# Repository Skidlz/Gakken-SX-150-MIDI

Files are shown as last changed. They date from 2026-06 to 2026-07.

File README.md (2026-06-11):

This project adds MIDI support to the Gakken SX-150 mk II using an Arduino R4.

This includes CCs for all original controls, plus additional parameters.

## Additional Hardware Features:
- Sustain and Release Stages (for existing hardware envelope)
- Inverted Envelope Mode
- Pulse, Dual Pulse, Super Saw, and other Waveforms
- Pulse Width Modulation
- Square and Triangle Sub Oscillators
- VCF Drive adjustment
- Envelope to VCF Depth Adjustment
- High Pass Filter Mode
- LFO to VCF Modulation
- Improved LFO sync
- VCA
- LED indicators for LFO and Envelope

## Additional Software Features:
 - Extra Software Envelopes with S/H
 - Extra Software LFOs
 - Pitch Bend
 - Portamento
 - Legato
 - Velocity-triggered Accent
 - Velocity Modulation
 - VCF Keytracking
 - Delay and Fade-in for Hardware LFO
 - Quantizing for Touchstrip

## Routing Diagram
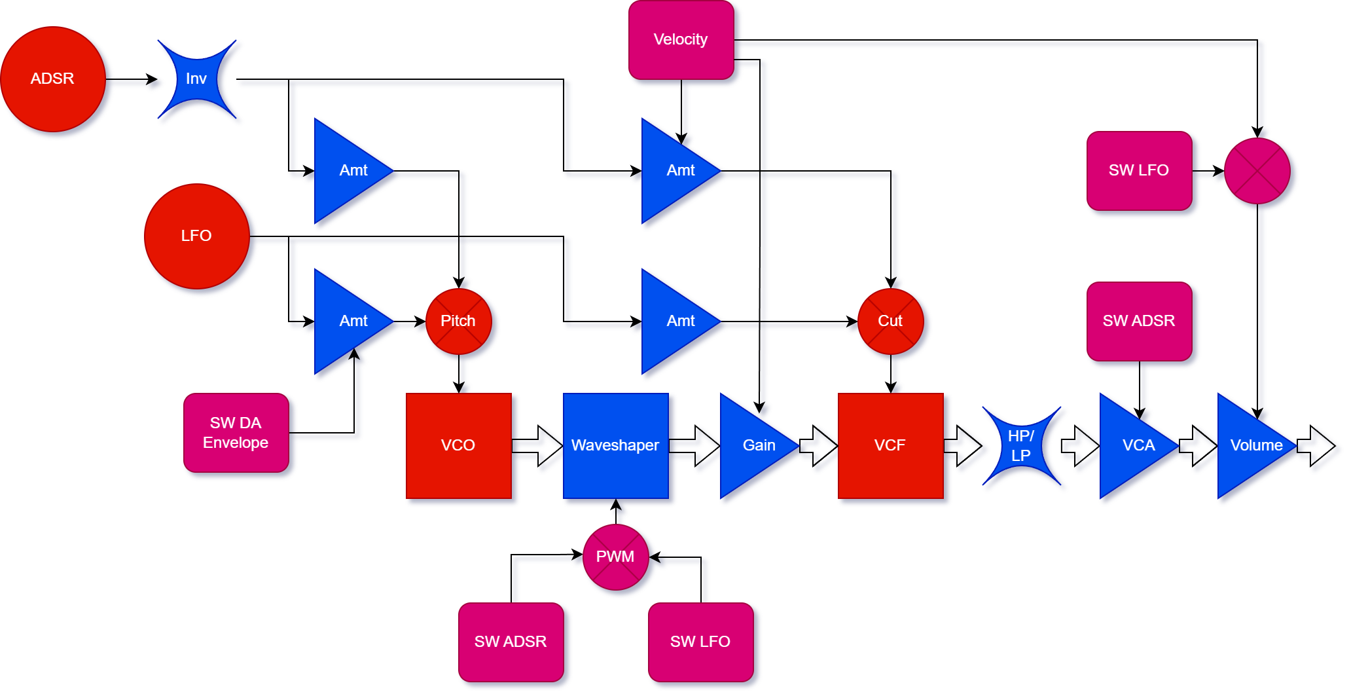
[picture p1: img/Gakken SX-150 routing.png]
Routing Diagram


## Schematic Diagram
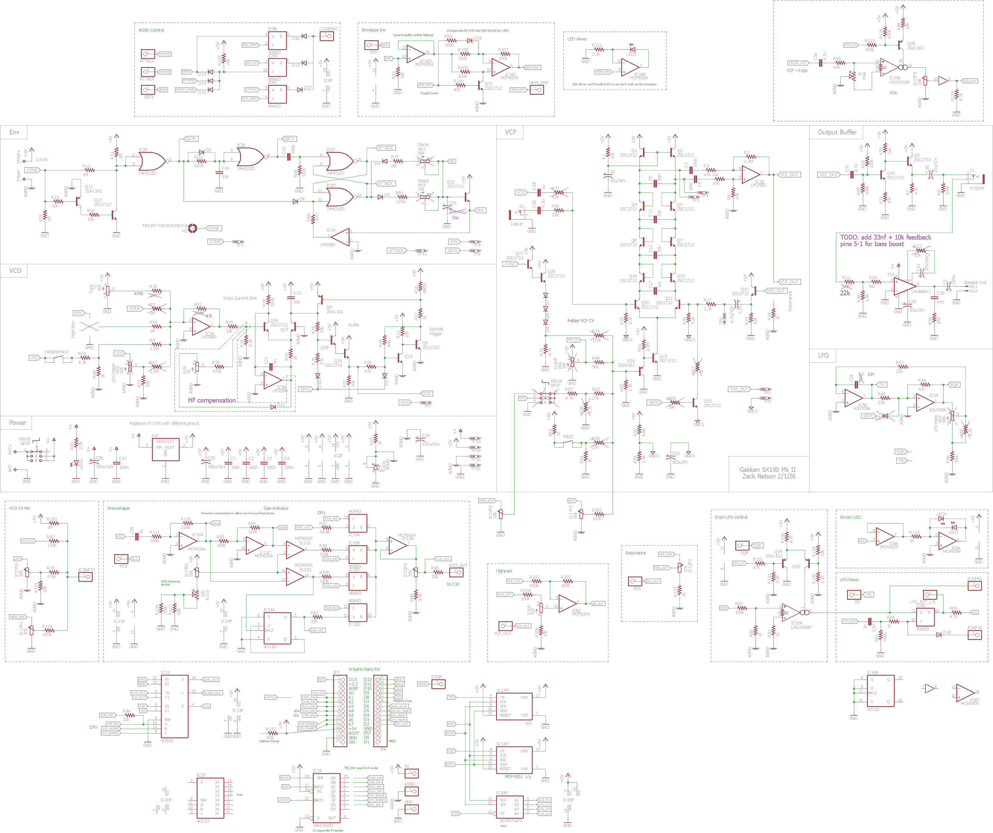
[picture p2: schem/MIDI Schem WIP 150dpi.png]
Schematic


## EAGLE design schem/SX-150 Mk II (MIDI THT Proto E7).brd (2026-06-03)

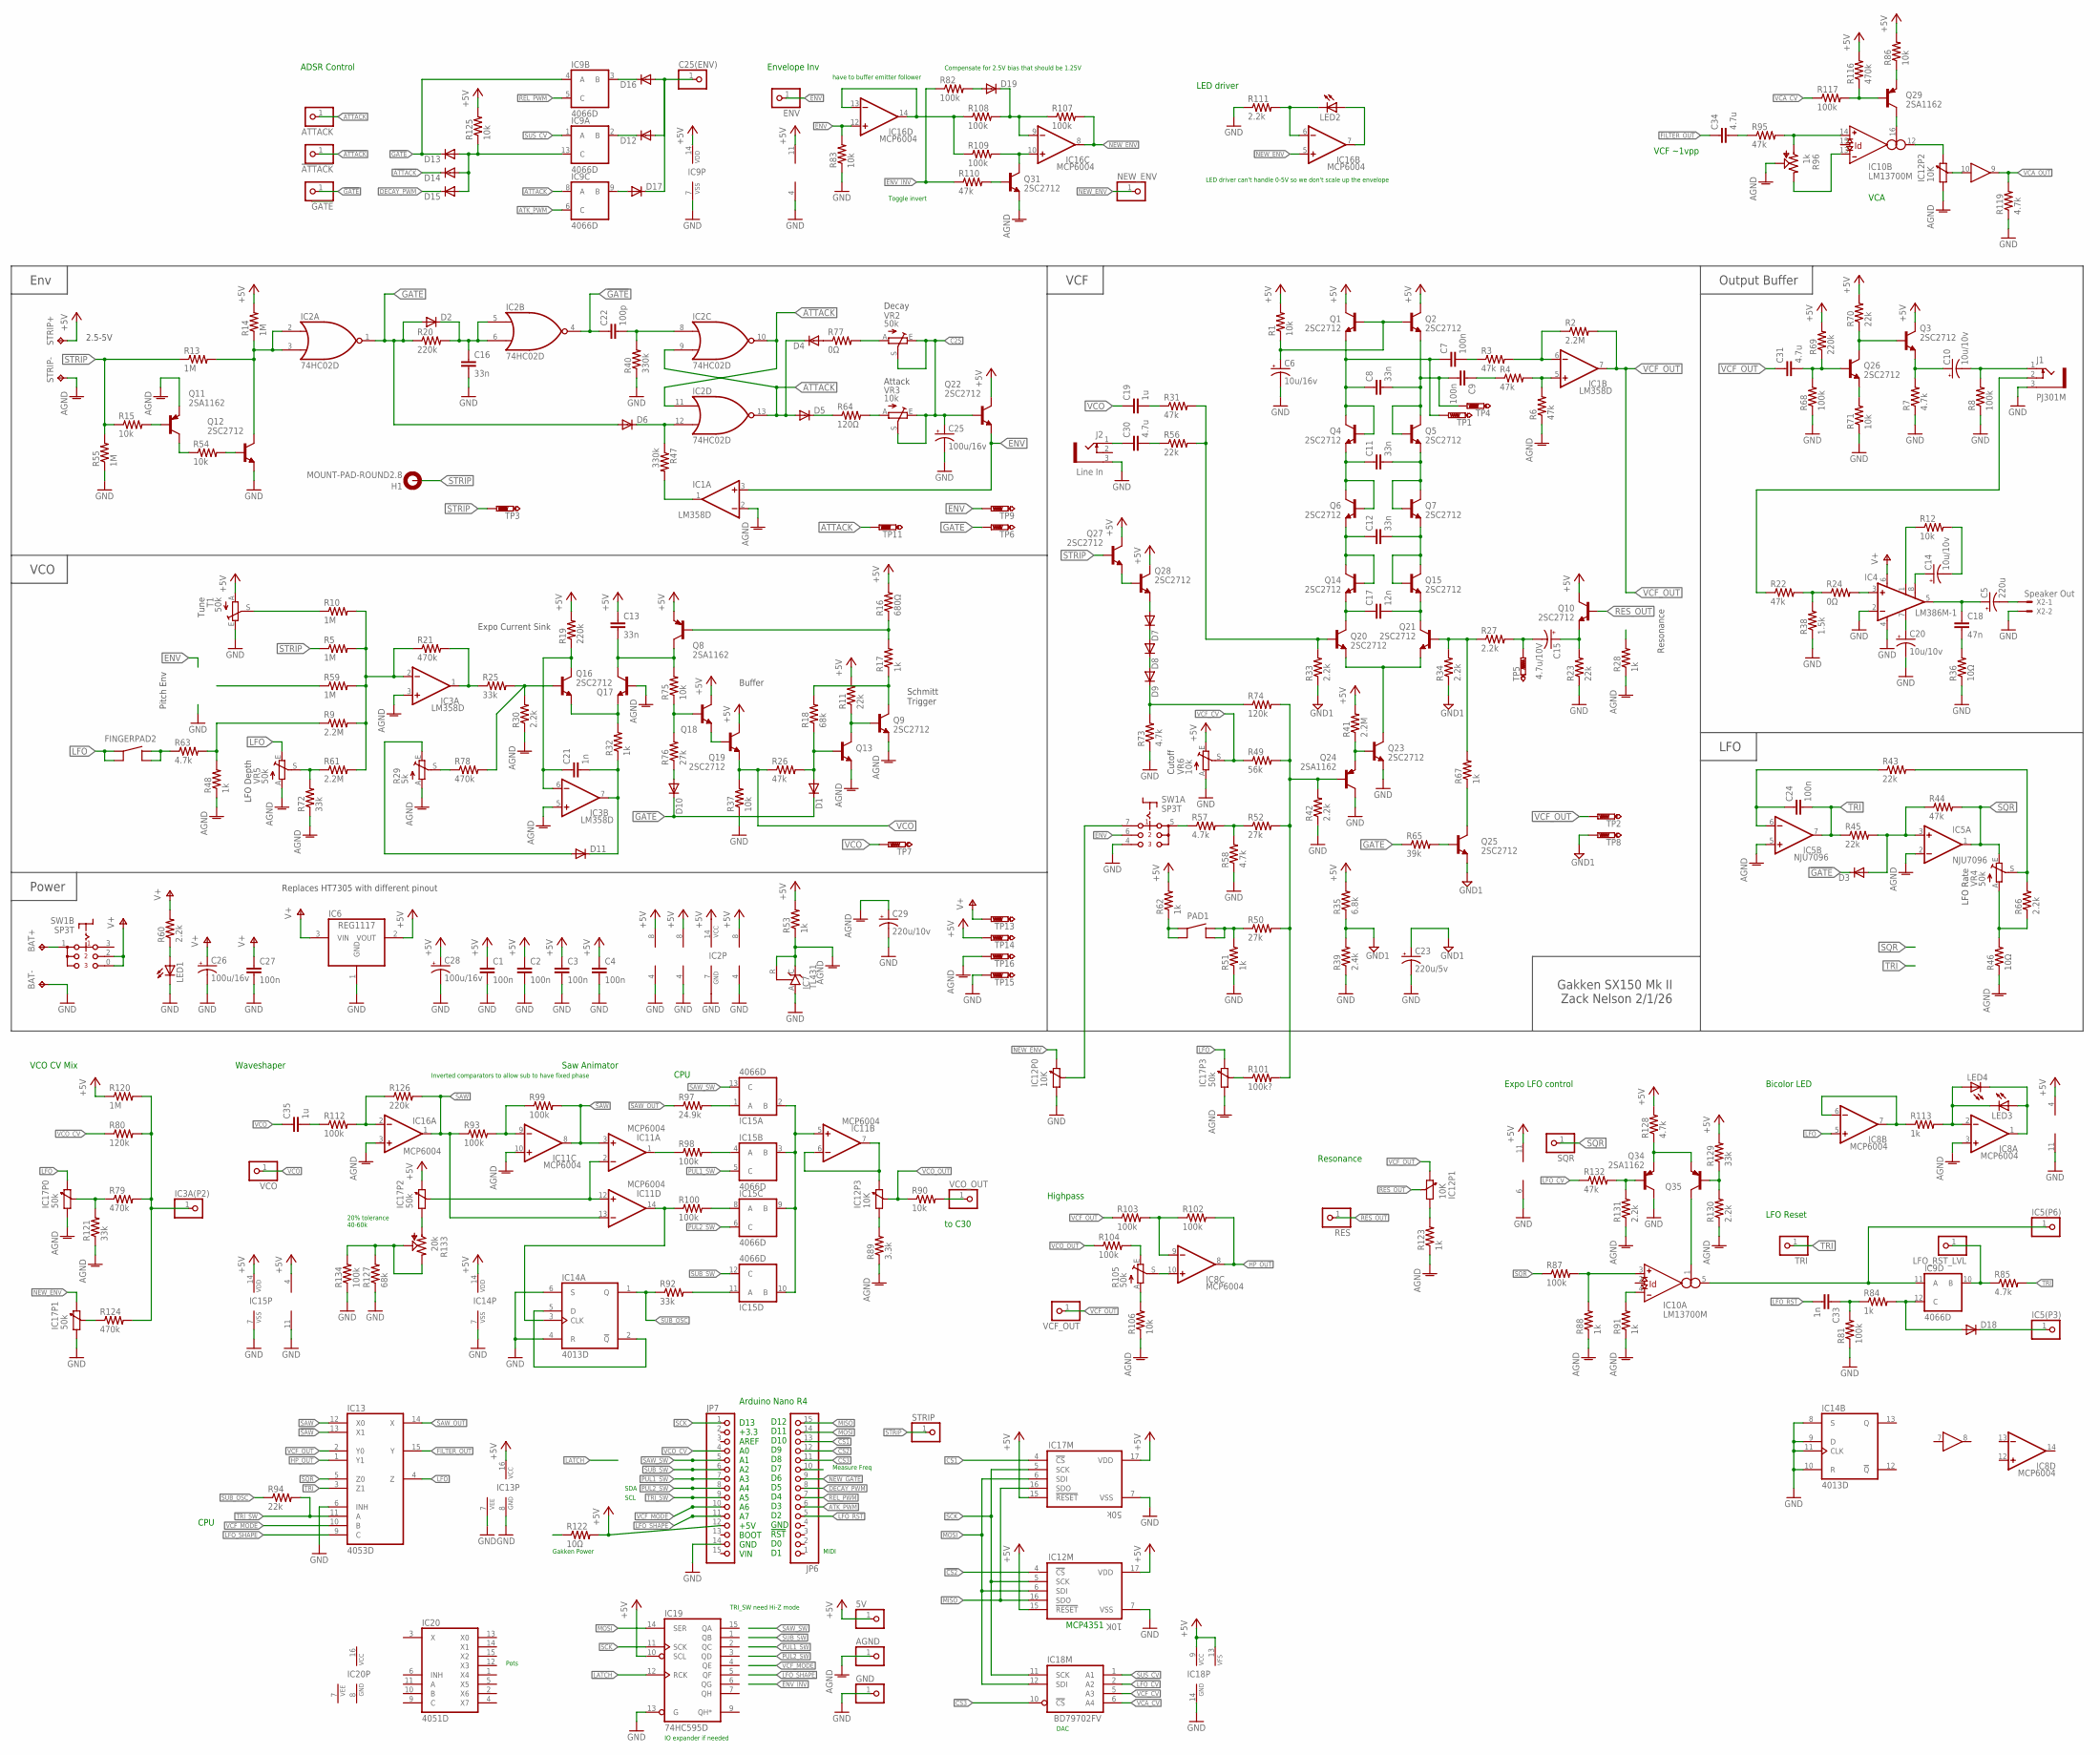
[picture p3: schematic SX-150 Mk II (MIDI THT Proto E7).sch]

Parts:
5V: PINHD-1X1; 1X01
!ATTACK: PINHD-1X1; 1X01
!GATE: PINHD-1X1; 1X01
AGND: PINHD-1X1; 1X01
ATTACK: PINHD-1X1; 1X01
BAT+: TPPAD1-13; P1-13
BAT-: TPPAD1-13; P1-13
C1, C2, C3, C4, C7, C9, C24, C27: 100n; C0603
C5: 220u; E2,5-6
C6: 10u/16v; E2,5-6
C8, C11, C12, C13, C16: 33n; C0603
C10, C14, C20: 10u/10v; E2,5-6
C15: 4.7u/10V; E2,5-6
C17: 12n; C0603
C18: 47n; C0603
C19, C35: 1u; C0603
C21, C33: 1n; C0603
C22: 100p; C0603
C23: 220u/5v; E2,5-6
C25, C26, C28: 100u/16v; E2,5-6
C25(ENV): PINHD-1X1; 1X01
C29: 220u/10v; E2,5-6
C30, C31, C34: 4.7u; C0603
D1, D10, D11: DIODE-DO41-7.6; DO41-7.6
D2, D3, D4, D5, D6, D7, D8, D9, D12, D13, D14, D15, D16, D17, D18, D19: DIODE-MINIMELF; MINIMELF
ENV: PINHD-1X1; 1X01
FINGERPAD2: GAKKEN-PAD
GND: PINHD-1X1; 1X01
H1: MOUNT-PAD-ROUND2.8; 2,8-PAD
IC1, IC3: LM358D; SO08
IC2: 74HC02D; SO14
IC3A(P2), IC5(P3), IC5(P6): PINHD-1X1; 1X01
IC4: LM386M-1; SO08
IC5: NJU7096; SO08
IC6: REG1117; SOT223
IC7: TL431; TO92-CLP
IC8, IC11, IC16: MCP6004; SO14
IC9, IC15: 4066D; SO14
IC10: LM13700M; SO16
IC12: 10K; TSSOP20_MC_MCH
IC13: 4053D; SO16
IC14: 4013D; SO14
IC17: 50k; TSSOP20_MC_MCH
IC18: BD79702FV; TSSOP14
IC19: 74HC595D; SO16
IC20: 4051D; SO16
J1: PJ301M; JACK-3.5-NOHOLE
J2: Line In; JACK-3.5-NOHOLE
JP6, JP7: PINHD-1X15; 1X15
LED1, LED2, LED3, LED4: LED3MM
LFO_RST_LVL: PINHD-1X1; 1X01
NEW_ENV: PINHD-1X1; 1X01
PAD1: GAKKEN-PAD
Q1, Q2, Q3, Q4, Q5, Q6, Q7, Q9, Q10, Q12, Q13, Q14, Q15, Q16, Q17, Q18, Q19, Q20, Q21, Q22, Q23, Q25, Q26, Q27, Q28, Q31: 2SC2712; SOT23-BEC
Q8, Q11, Q24, Q29, Q34, Q35: 2SA1162; SOT23-BEC
R1, R12, R15, R37, R54, R71, R75, R83, R86, R90, R106, R125: 10k; R0603
R2, R9, R41, R61: 2.2M; R0603
R3, R4, R6, R22, R26, R31, R44, R95, R110, R132: 47k; R0603
R5, R10, R13, R14, R55, R59, R120: 1M; R0603
R7, R57, R58, R63, R73, R85, R119, R128: 4.7k; R0603
R8, R68, R81, R82, R87, R93, R98, R99, R100, R102, R103, R104, R107, R108, R109, R112, R117, R134: 100k; R0603
R11, R23, R43, R45, R56, R70, R94: 22k; R0603
R16: 680Ω; R0603
R17, R28, R32, R48, R51, R53, R62, R67, R84, R88, R91, R113, R123: 1k; R0603
R18, R127: 68k; R0603
R19, R20, R69, R126: 220k; R0603
R21, R78, R79, R116, R124: 470k; R0603
R24, R77: 0Ω; R0603
R25, R72, R92, R121, R129: 33k; R0603
R27, R30, R33, R34, R42, R60, R66, R111, R130, R131: 2.2k; R0603
R29: 5k; B25P
R35: 6.8k; R0603
R36, R46, R122: 10Ω; R0603
R38: 1.5k; R0603
R39: 2.4k; R0603
R40, R47: 330k; R0603
R49: 56k; R0603
R50, R52, R76: 27k; R0603
R64: 120Ω; R0603
R65: 39k; R0603
R74, R80: 120k; R0603
R89: 3.3k; R0603
R96: 1k; B25P
R97: 24.9k; R0603
R101: 100k?; R0603
R105: 50k; B25P
R133: 20k; B25P
RES: PINHD-1X1; 1X01
SQR: PINHD-1X1; 1X01
STRIP: PINHD-1X1; 1X01
STRIP+: TPB2,54; B2,54
STRIP-: TPB2,54; B2,54
SW1: SP3T
T1: 50k; CA9V
TP1, TP2, TP3, TP4, TP5, TP6, TP7, TP8, TP9, TP11, TP13, TP14, TP15, TP16: PTR1B1,27; B1,27
TRI: PINHD-1X1; 1X01
VCF_OUT: PINHD-1X1; 1X01
VCO: PINHD-1X1; 1X01
VCO_OUT: PINHD-1X1; 1X01
VR2, VR4, VR5: 50k; CA9V
VR3, VR6: 10k; CA9V
X2: Speaker Out; 22-23-2021

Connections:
!ATTACK: !ATTACK.1, D14.C, IC2.10 (O), IC2.11 (I0)
!CS1: IC17.4 (!CS), JP6.13
!CS2: IC12.4 (!CS), JP6.12
!CS3: IC18.10 (!CS), JP6.11
!GATE: !GATE.1, C22.1, D1.C, D3.C, D10.C, D13.C, IC2.4 (O), IC9.4 (A)
!SAW: IC11.3 (+IN), IC11.8 (OUT), IC13.13 (X1), R99.2
+5V: 5V.1, C1.1, C2.1, C3.1, C4.1, C13.1, C28.+, IC1.8 (V+), IC2.14 (VCC), IC3.8 (V+), IC5.8 (V+), IC6.2 (VOUT), IC8.4 (V+), IC9.14 (VDD), IC10.11 (V+), IC11.4 (V+), IC12.15 (!RESET), IC12.17 (VDD), IC13.16 (VCC), IC14.14 (VDD), IC15.14 (VDD), IC16.11 (V-), IC17.15 (!RESET), IC17.17 (VDD), IC17.18 (B), IC18.9 (VCC), IC18.13 (VFS), IC19.10 (SCL), JP7.12, Q1.C, Q2.C, Q3.C, Q8.E, Q10.C, Q18.C, Q19.C, Q22.C, Q27.C, Q28.C, R1.2, R11.2, R14.2, R16.2, R19.2, R35.2, R41.2, R53.2, R62.2, R69.2, R70.2, R86.2, R116.2, R120.1, R122.2, R125.2, R128.2, R129.2, STRIP+.TP, T1.A, TP14.TP, VR6.E
AGND: AGND.1, C29.+, IC1.2 (-IN), IC3.3 (+IN), IC3.5 (+IN), IC5.2 (-IN), IC5.5 (+IN), IC7.C, IC7.R, IC8.3 (+IN), IC11.10 (+IN), IC12.20 (A), IC16.3 (+IN), IC17.1 (A), IC17.11 (A), Q9.E, Q11.E, Q13.E, Q17.B, Q31.E, R6.1, R28.1, R29.A, R30.1, R46.1, R48.1, R53.1, R72.1, R88.1, R89.1, R91.1, R96.S, R106.1, R121.1, R123.1, R130.1, R131.1, STRIP-.TP, TP16.TP, VR5.A
ATK_PWM: IC9.6 (C), JP6.6
ATTACK: ATTACK.1, D4.C, D5.A, IC2.9 (I1), IC2.13 (O), IC9.8 (A), TP11.TP
C25: C25.+, C25(ENV).1, D12.A, D16.A, D17.C, Q22.B, VR2.E, VR2.S, VR3.E, VR3.S
DECAY_PWM: D15.C, JP6.8
ENV: ENV.1, IC1.3 (+IN), IC16.12 (+IN), Q22.E, R83.2, SW1.6 (T2), TP9.TP
ENV_INV: R82.1, R110.1
FILTER_OUT: C34.1, IC13.15 (Y)
GATE: D2.A, D6.A, IC2.1 (O), R20.1, R65.1, TP6.TP
GND: BAT-.TP, C1.2, C2.2, C3.2, C4.2, C6.-, C16.2, C20.-, C23.-, C25.-, C26.-, C27.2, C28.-, C29.-, GND.1, IC1.4 (V-), IC2.7 (GND), IC3.4 (V-), IC4.2 (-IN), IC4.4 (GND), IC5.4 (V-), IC6.1 (GND), IC7.A, IC8.11 (V-), IC9.7 (VSS), IC10.6 (V-), IC11.11 (V-), IC12.7 (VSS), IC12.11 (A), IC13.6 (INH), IC13.7 (VEE), IC13.8 (GND), IC14.4 (R), IC14.6 (S), IC14.7 (VSS), IC14.8 (S), IC14.9 (D), IC14.10 (R), IC14.11 (CLK), IC15.7 (VSS), IC16.4 (V+), IC17.7 (VSS), IC17.10 (A), IC18.14 (GND), IC19.8 (GND), IC19.13 (G), IC20.8 (GND), J1.3 (1), J2.3 (1), JP7.14, LED1.K (C), Q12.E, Q23.E, Q24.C, Q34.C, R7.1, R8.1, R23.1, R36.1, R37.1, R38.1, R39.1, R40.1, R42.1, R51.1, R55.1, R58.1, R68.1, R71.1, R73.1, R81.1, R83.1, R111.1, R119.1, R127.1, R134.1, SW1.4 (T3), T1.E, TP15.TP, VR6.A, X2.2
GND1: C23.+, Q25.E, R33.1, R34.1, R35.1, R39.2, TP8.TP
HP_OUT: IC8.8 (OUT), IC13.1 (Y1), R102.2
LATCH: IC19.12 (RCK)
LFO: FINGERPAD2.A0, FINGERPAD2.A1, IC8.5 (+IN), IC13.4 (Z), IC17.3 (B), IC17.13 (B), VR5.E
LFO_CV: IC18.2 (A2), R132.1
LFO_RST: C33.2, JP6.5
LFO_SHAPE: IC13.9 (C), JP7.11
MISO: IC12.16 (SDO), IC17.16 (SDO), JP6.15
MOSI: IC12.6 (SDI), IC17.6 (SDI), IC18.12 (SDI), IC19.14 (SER), JP6.14
unnamed: IC1.1 (OUT), R47.2
unnamed: D5.C, R64.1
unnamed: IC2.2 (I0), IC2.3 (I1), Q12.C, R13.2, R14.1
unnamed: D12.C, IC9.2 (B)
unnamed: C22.2, IC2.8 (I0), R40.2
unnamed: Q12.B, R54.2
unnamed: C16.1, D2.C, IC2.5 (I0), IC2.6 (I1), R20.2
unnamed: D6.C, IC2.12 (I1), R47.1
unnamed: D4.A, R77.1
unnamed: D17.A, IC9.9 (B)
unnamed: R64.2, VR3.A
unnamed: D19.A, R82.2
unnamed: Q11.C, R54.1
unnamed: Q11.B, R15.2
unnamed: R61.1, R72.2, VR5.S
unnamed: IC5(P6).1, IC9.11 (A), IC10.5 (OUT)
unnamed: IC3.2 (-IN), R5.2, R9.2, R10.2, R21.1, R59.2, R61.2
unnamed: D18.C, IC5(P3).1
unnamed: R46.2, R66.1, VR4.A
unnamed: R43.2, R66.2, VR4.S
unnamed: IC3.1 (OUT), R21.2, R25.1
unnamed: Q16.B, R25.2, R30.2, R78.2
unnamed: R9.1, R48.2, R63.2
unnamed: R10.1, T1.S
unnamed: C13.2, Q8.C, Q17.C, R75.2
unnamed: Q8.B, R16.1, R17.2
unnamed: C21.2, D11.C, IC3.7 (OUT), R32.1
unnamed: Q16.E, Q17.E, R32.2
unnamed: C21.1, IC3.6 (-IN), Q16.C, R19.1
unnamed: Q9.C, R17.1, R18.2
unnamed: Q18.B, R75.1, R76.2
unnamed: Q18.E, Q19.B
unnamed: BAT+.TP, SW1.1
unnamed: Q9.B, Q13.C, R11.1
unnamed: D1.A, Q13.B, R18.1, R26.2
unnamed: D10.A, R76.1
unnamed: C7.1, C8.1, Q1.E, Q4.B, Q4.C, TP1.TP
unnamed: C8.2, C9.2, Q2.E, Q5.B, Q5.C, TP4.TP
unnamed: C6.+, Q1.B, Q2.B, R1.1
unnamed: Q20.E, Q21.E, Q23.C
unnamed: C11.1, Q4.E, Q6.B, Q6.C
unnamed: C11.2, Q5.E, Q7.B, Q7.C
unnamed: Q20.B, R31.2, R33.2, R56.2
unnamed: C12.1, Q6.E, Q14.B, Q14.C
unnamed: C12.2, Q7.E, Q15.B, Q15.C
unnamed: C17.1, Q14.E, Q20.C
unnamed: C17.2, Q15.E, Q21.C
unnamed: Q21.B, R27.1, R34.2, R67.2
unnamed: C7.2, R3.1
unnamed: C9.1, R4.1
unnamed: IC1.6 (-IN), R2.1, R3.2
unnamed: IC1.5 (+IN), R4.2, R6.2
unnamed: Q23.B, Q24.E, R41.1
unnamed: Q25.C, R67.1
unnamed: Q25.B, R65.2
unnamed: C15.-, R27.2, TP5.TP
unnamed: C15.+, Q10.E, R23.2
unnamed: IC17.9 (W), R124.1
unnamed: Q29.E, R86.1
unnamed: Q24.B, R42.2, R49.2, R50.2, R52.2, R74.2, R101.2
unnamed: R57.1, SW1.5 (P1)
unnamed: C35.2, R112.1
unnamed: R52.1, R57.2, R58.2
unnamed: PAD1.B0, PAD1.B1, R50.1, R51.2
unnamed: C19.2, R31.1
unnamed: C30.2, R56.1
unnamed: C30.1, J2.1 (2)
unnamed: C31.2, Q26.B, R68.2, R69.1
unnamed: Q3.B, Q26.C, R70.1
unnamed: Q26.E, R71.2
unnamed: C10.+, Q3.E, R7.2
unnamed: C10.-, J1.1 (2), R8.2
unnamed: Q27.E, Q28.B
unnamed: PAD1.A0, PAD1.A1, R62.1
unnamed: D7.A, Q28.E
unnamed: D7.C, D8.A
unnamed: D8.C, D9.A
unnamed: D9.C, R73.2, R74.1
unnamed: FINGERPAD2.B0, FINGERPAD2.B1, R63.1
unnamed: C20.+, IC4.7 (BYPASS)
unnamed: C14.+, IC4.8 (GAIN)
unnamed: IC4.1 (GAIN), R12.1
unnamed: C14.-, R12.2
unnamed: C5.+, C18.1, IC4.5 (OUT)
unnamed: IC4.3 (+IN), R24.2
unnamed: C5.-, X2.1
unnamed: J1.2 (3), R22.1
unnamed: C18.2, R36.2
unnamed: D11.A, R29.E
unnamed: R22.2, R24.1, R38.2
unnamed: LED1.A, R60.1
unnamed: IC10.16 (IABC), Q29.C
unnamed: R29.S, R78.1
unnamed: D13.A, D14.A, D15.A, IC9.13 (C), R125.1
unnamed: C24.1, IC5.6 (-IN), R43.1
unnamed: D19.C, IC16.9 (-IN), R107.1, R108.2
unnamed: D16.C, IC9.3 (B)
unnamed: R77.2, VR2.A
unnamed: D18.A, IC9.12 (C), R84.2
unnamed: IC11.1 (OUT), R98.1
unnamed: IC8.10 (+IN), R105.S
unnamed: IC16.13 (-IN), IC16.14 (OUT), R108.1, R109.1
unnamed: C33.1, R81.2, R84.1
unnamed: IC14.2 (!Q), IC14.5 (D)
unnamed: IC12.12 (W), SW1.7 (T1)
unnamed: IC10.3 (+IN), R87.2, R88.2
unnamed: IC10.4 (-IN), R91.2
unnamed: IC15.1 (A), R97.2
unnamed: IC15.4 (A), R98.2
unnamed: IC15.8 (A), R100.2
unnamed: IC10.14 (+IN), R95.2, R96.A
unnamed: IC12.1 (A), R89.2
unnamed: IC9.10 (B), LFO_RST_LVL.1, R85.1
unnamed: IC11.5 (+IN), IC15.2 (B), IC15.3 (B), IC15.9 (B), IC15.10 (B)
unnamed: IC10.13 (-IN), R96.E
unnamed: IC15.11 (A), R92.2
unnamed: IC11.6 (-IN), IC11.7 (OUT), IC12.3 (B)
unnamed: IC11.9 (-IN), R93.2, R99.1
unnamed: IC11.14 (OUT), IC14.3 (CLK), R100.1
unnamed: C34.2, R95.1
unnamed: IC8.9 (-IN), R102.1, R103.2
unnamed: Q29.B, R116.1, R117.2
unnamed: R104.2, R105.E
unnamed: IC10.10 (IN), IC12.19 (W)
unnamed: R105.A, R106.2
unnamed: IC16.10 (+IN), Q31.C, R109.2
unnamed: IC17.20 (A), R133.A
unnamed: Q31.B, R110.2
unnamed: IC8.1 (OUT), LED3.A, LED4.K (C)
unnamed: R127.2, R133.E, R133.S, R134.2
unnamed: IC16.7 (OUT), LED2.A
unnamed: IC16.6 (-IN), LED2.K (C), R111.2
unnamed: IC8.2 (-IN), LED3.K (C), LED4.A, R113.2
unnamed: IC8.6 (-IN), IC8.7 (OUT), R113.1
unnamed: D3.A, IC5.3 (+IN), R44.1, R45.2
unnamed: IC17.2 (W), R101.1
unnamed: IC17.12 (W), R79.1, R121.2
unnamed: IC3A(P2).1, R79.2, R80.2, R120.2, R124.2
unnamed: IC10.12 (OUT), IC12.18 (B)
unnamed: IC12.10 (A), R123.2
unnamed: IC16.2 (-IN), R112.2, R126.1
unnamed: R90.2, VCO_OUT.1
unnamed: Q34.E, Q35.E, R128.1
unnamed: Q35.B, R129.1, R130.2
unnamed: Q34.B, R131.2, R132.2
unnamed: IC10.1 (IABC), Q35.C
NEW_ENV: IC12.13 (B), IC16.5 (+IN), IC16.8 (OUT), IC17.8 (B), NEW_ENV.1, R107.2
NEW_GATE: JP6.9
PUL1_SW: IC15.5 (C), JP7.7
PUL2_SW: IC15.6 (C), JP7.8
REL_PWM: IC9.5 (C), JP6.7
RES_OUT: IC12.9 (W), Q10.B, RES.1
SAW: IC11.13 (-IN), IC13.12 (X0), IC16.1 (OUT), R93.1, R126.2
SAW_CV: IC11.2 (-IN), IC11.12 (+IN), IC17.19 (W)
SAW_OUT: IC13.14 (X), R97.1
SAW_SW: IC15.13 (C), JP7.5
SCK: IC12.5 (SCK), IC17.5 (SCK), IC18.11 (SCK), IC19.11 (SCK), JP7.1
SQR: IC5.1 (OUT), IC13.5 (Z0), R44.2, R87.1, SQR.1, VR4.E
STRIP: H1.B2,8, Q27.B, R5.1, R13.1, R15.1, R55.2, STRIP.1, TP3.TP
SUB_OSC: IC14.1 (Q), R92.1, R94.1
SUB_SW: IC15.12 (C), JP7.6
SUS_CV: IC9.1 (A), IC18.1 (A1)
TRI: C24.2, IC5.7 (OUT), IC13.3 (Z1), R45.1, R85.2, TRI.1
TRI_SW: IC13.11 (A), JP7.9, R94.2
V+: C26.+, C27.1, IC4.6 (VS), IC6.3 (VIN), R60.2, SW1.0 (T3), SW1.2 (T2), TP13.TP
VCA_CV: IC18.6 (A4), R117.1
VCA_OUT: IC10.9 (OUT), R119.2
VCC: IC19.16 (VCC), IC20.16 (VCC)
VCF_CV: IC18.5 (A3), R49.1, VR6.S
VCF_MODE: IC13.10 (B), JP7.10
VCF_OUT: C31.1, IC1.7 (OUT), IC12.8 (B), IC13.2 (Y0), R2.2, R103.1, TP2.TP, VCF_OUT.1
VCO: C19.1, C35.1, Q19.E, R26.1, R37.2, TP7.TP, VCO.1
VCO_CV: JP7.4, R80.1
VCO_OUT: IC12.2 (W), R90.1, R104.1
VEE: IC20.7 (VEE)

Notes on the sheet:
Decay
Attack
2.5-5V
LFO Rate
Expo Current Sink
Buffer
Schmitt Trigger
VCO
LFO Depth
Cutoff
Replaces HT7305 with different pinout
Env
VCF
LFO
Output Buffer
Power
Gakken SX150 Mk II Zack Nelson 2/1/26
Resonance
Pitch Env
Tune
LFO Reset
Expo LFO control
Saw Animator
CPU
Highpass
Bicolor LED
LED driver
VCF ~1vpp
MCP4351
VCA
D12 D11 D10 D9 D8 D7 D6 D5 D4 D3 D2 GND !RST D0 D1
D13 +3.3 AREF A0 A1 A2 A3 A4 A5 A6 A7 +5V BOOT GND VIN
Gakken Power
Measure Freq
to C30
MIDI
IO expander if needed
Inverted comparators to allow sub to have fixed phase
TRI_SW need Hi-Z mode
have to buffer emitter follower

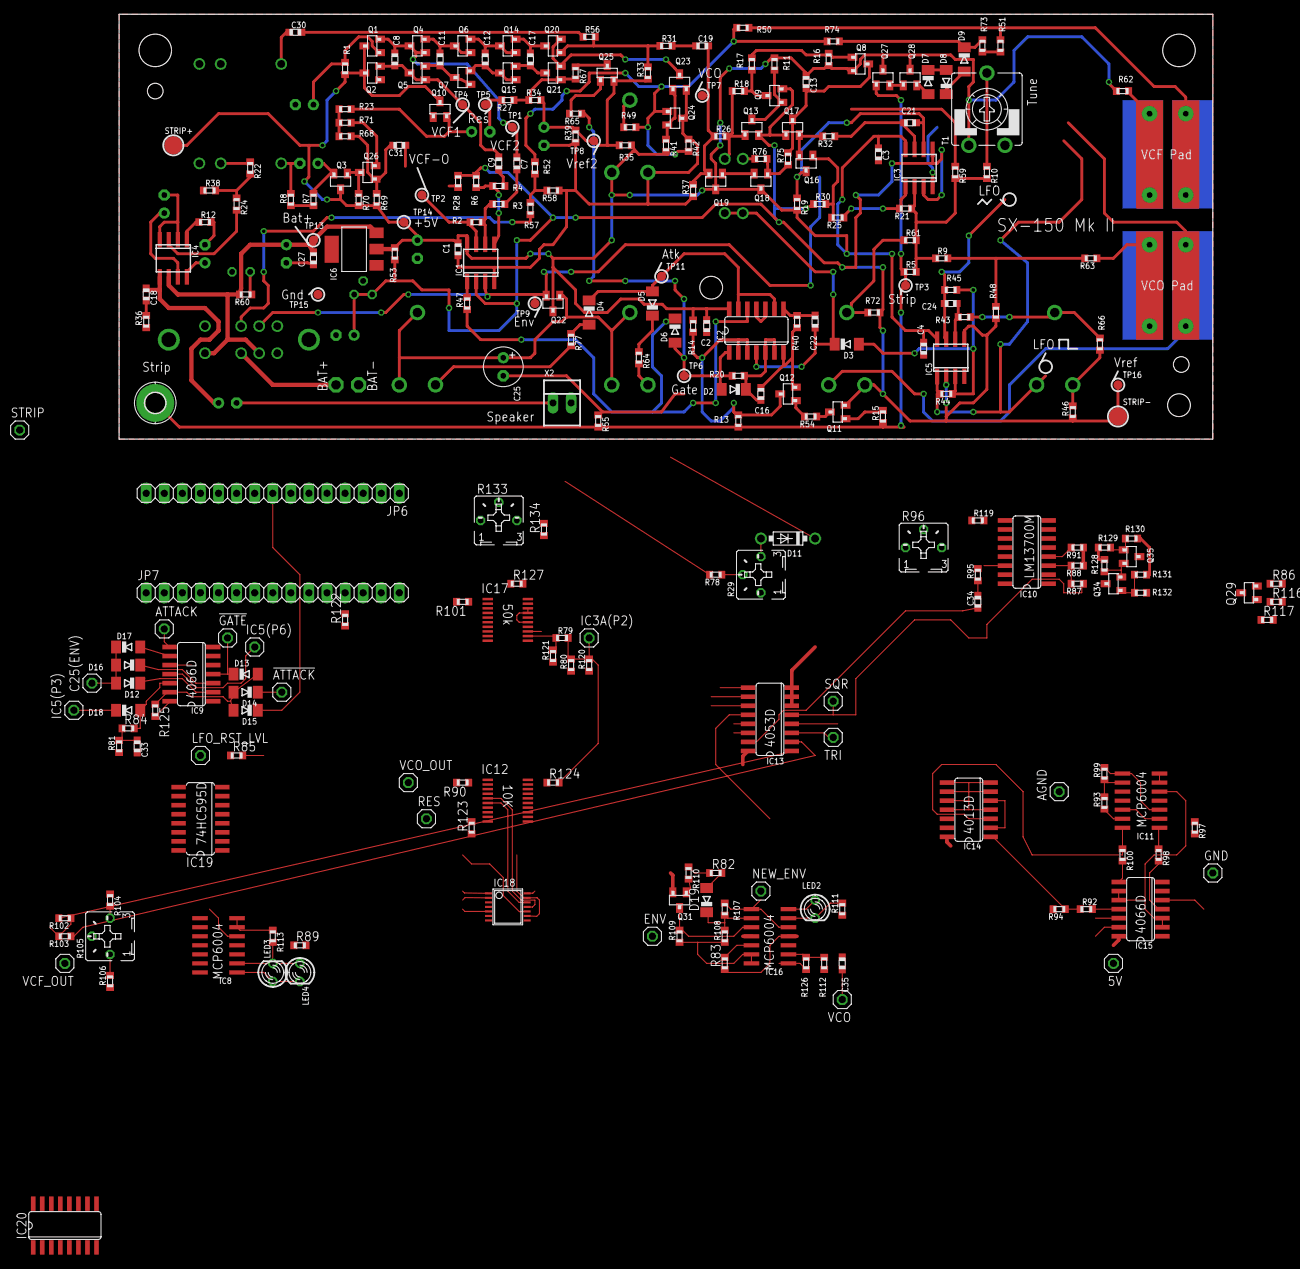
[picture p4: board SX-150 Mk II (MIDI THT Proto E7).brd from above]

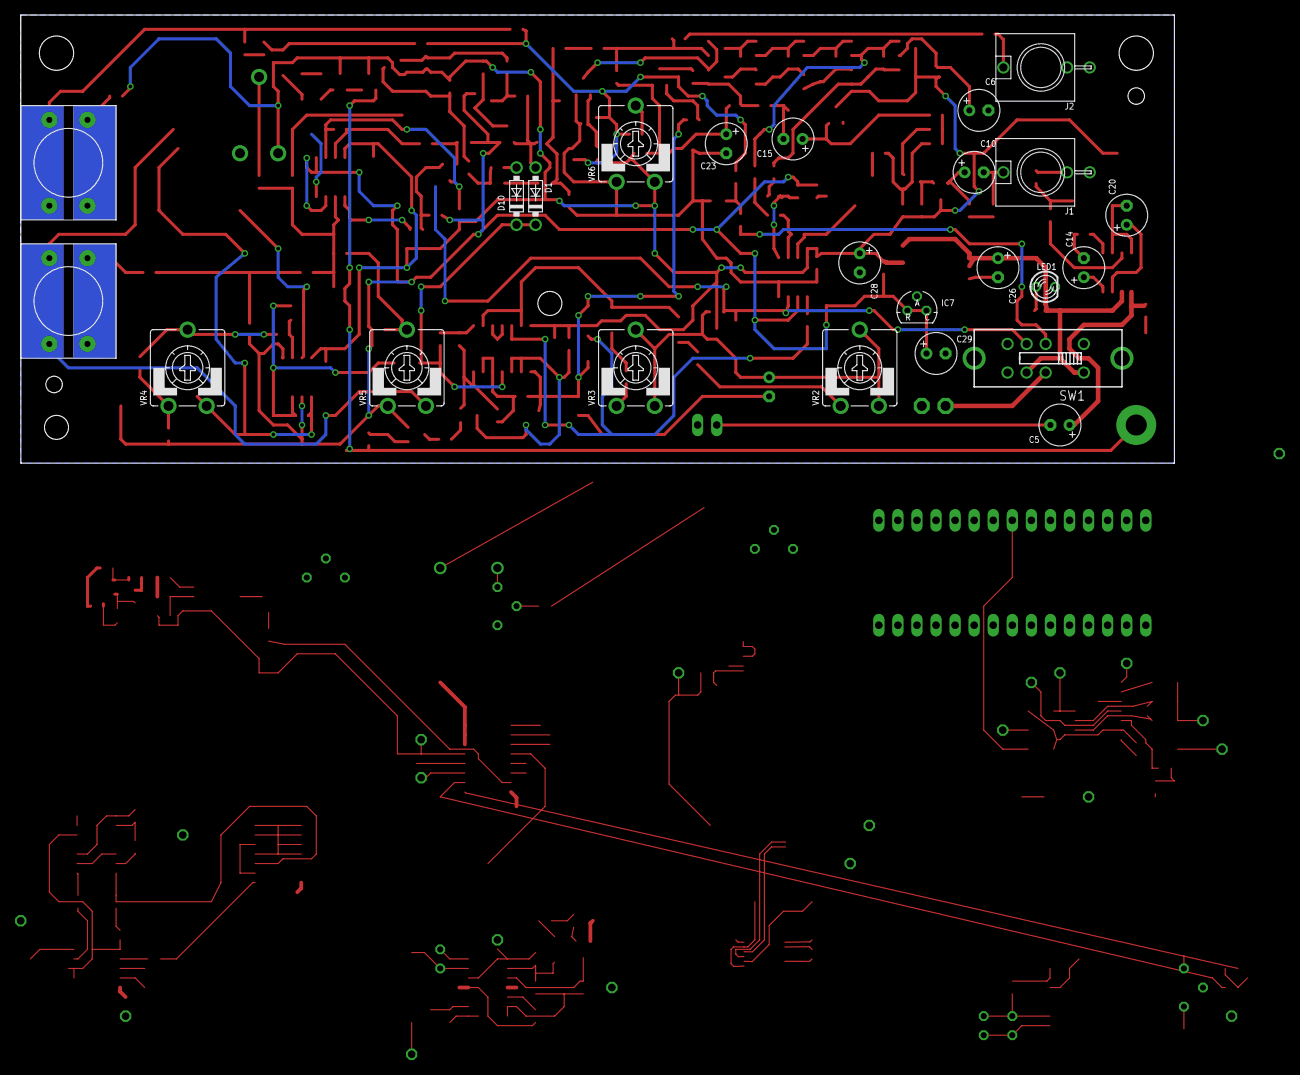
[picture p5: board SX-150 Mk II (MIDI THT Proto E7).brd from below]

Board: 2 copper layers, 153.7 x 59.7 mm, 293 parts (24 on the bottom side), 198 nets.

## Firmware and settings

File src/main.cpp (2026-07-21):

#include <Arduino.h>
//#include <U8g2lib.h>
#include "FspTimer.h"
#include "midi.h"
#include "hw_adsr.h"
#include "voice.h"
#include "MCP4251.h" //Digipot
#include "BD79702.h" //DAC
#include "analogInputs.h"
#include "parameter.h"
#include "noteAssigner.h"

constexpr float x = 0.51; //sets the middle of the curve on x-axis
constexpr float k = 3.8; //sets the curve severity
//x0: sets middle of the curve on x-axis, k: sets curve steepness
std::function<float(float)> makeSCurveClosure(float x0, float k) {
    //precompute offset and denominator
    float offset = 1 / (1 + exp(-k * (0 - x0)));
    float scale = 1 / (1 / (1 + exp(-k * (1 - x0))) - offset);

    //return lambda that will apply s-curve to compensate for imperfect log approximation circuit
    return [x0, k, offset, scale](float position) {
        float sCurve = 1 / (1 + exp(-k * (position - x0)));
        return (sCurve - offset) * scale;
    };
}

//Hardware IO--------------------------------------------------------------------------------------
BD79702 DAC0(8);
Dac sustainDac = DAC0.getChannel(BD79702::AO1);
Dac lfoRateDac = DAC0.getChannel(BD79702::AO2);
Dac vcfCutDac = DAC0.getChannel(BD79702::AO3);
Dac vcaDac = DAC0.getChannel(BD79702::AO4);

MCP4251 digiPot1; //50k
DigiPot lfoToPitchPot = digiPot1.getChannel(MCP4251::POT0, { true, true, makeSCurveClosure(0.51, 3.8) });
DigiPot envToPitchPot = digiPot1.getChannel(MCP4251::POT1, { .invert = false, .disconnectAtMin = true });
DigiPot pwmPot = digiPot1.getChannel(MCP4251::POT2, { .invert = true });
DigiPot lfoToVcfPot = digiPot1.getChannel(MCP4251::POT3, { .invert = false, .disconnectAtMin = true });

MCP4251 digiPot2(9); //10k
DigiPot envToVcfPot = digiPot2.getChannel(MCP4251::POT0, { .invert = true });
DigiPot resonancePot = digiPot2.getChannel(MCP4251::POT1, { .invert = true });
DigiPot volumePot = digiPot2.getChannel(MCP4251::POT2);
DigiPot vcfDrivePot = digiPot2.getChannel(MCP4251::POT3, { .invert = true });

HW_ADSR adsr(D3, D5, D4, sustainDac);

touchStrip touchStrip;

Voice voice(vcfCutDac, resonancePot, vcfDrivePot, pwmPot, lfoRateDac, adsr);

//timer
FspTimer tickTimer; //GPT4
bool stepFlag = false; //modulation tick
void tickClock(timer_callback_args_t *args) { stepFlag = true; }

//128x32 I2C OLED on pins A4 (data) & A5 (clock)
//U8G2_SSD1306_128X32_UNIVISION_F_HW_I2C u8g2(U8G2_R0, U8X8_PIN_NONE);
//const char *const noteNames[12] = { "A", "A#/Bb", "B", "C", "C#/Db", "D", "D#/Eb", "E", "F", "F#/Gb", "G", "G#/Ab" };

//MIDI callbacks-----------------------------------------------------
MIDI midi;
void midiCcHandler(uint8_t key, uint8_t ptr);

void setup() {
    Serial1.begin(31250); //MIDI baud
    Serial.begin(115200); //debug port

    //Terminal needs RTS/CTS flow to work!
//    delay(1000); //let serial connect
//    while (!Serial) {} //wait for debug serial port to connect

    //sort modulators in routes for processing by voice.update()
    voice.evalRoutes();

    HW_VCO::initTimer(); //start timer for measuring frequency

    analogWriteResolution(12); //change DAC to 12-bit resolution

    DAC0.begin();

    //Digipot--------------------------------------------------------
    digiPot1.begin();
    pwmPot.write(1); //max
    lfoToPitchPot.write(0); //min
    envToVcfPot.write(.5); //Env to VCF

    digiPot2.begin();
    resonancePot.write(.1);
    vcfDrivePot.write(0);

    adsr.begin(); //starts PMW timers
    voice.osc.calibrate(); //call CV calibration routine

//    u8g2.begin(); //start OLED
//    u8g2.setPowerSave(true); //turn display off

    //NVIC_DisableIRQ(AGT0_INT_IRQn);

    //log a series of measurements for HF trim adjustment
//    osc.start();
//    for (uint16_t note = 24; note <= 108; note++) {
//        osc.setNote(note);
//        delay(100);
//        float mes = osc.measureFreq();
//        Serial.println(mes, 3);
//    }
//    osc.stop();

    //set up GPT4 timer to interrupt at 4kHz. this is the tick for the modulators
    tickTimer.begin(TIMER_MODE_PERIODIC, GPT_TIMER, 4, 4000.0f, 0.0f, tickClock);
    tickTimer.setup_overflow_irq();
    tickTimer.open();
    tickTimer.start();

    //MIDI callbacks
    midi.noteOn = NoteAssigner::noteOnHandler;
    midi.noteOff = NoteAssigner::noteOffHandler;
    midi.controlChange = midiCcHandler;
    midi.pitchBend = [](int16_t bend) { voice.setPitchBend(bend); };

    //set touchstrip callbacks--------------------------------------
    touchStrip.pressedCB = [](float reading){
        voice.noteOn(touchStrip::scaleNote(reading), 100);
    };

    touchStrip.updatedCB = [](float reading){
        voice.osc.setNoteHW(touchStrip::scaleNote(reading)); //play note
    };

    touchStrip.releasedCB = [](float reading){
        float scaledNote = touchStrip::scaleNote(reading);
        voice.noteOff(scaledNote, 100);
        voice.osc.setNoteHW(scaledNote);
    };

    //Init patch
    voice.lfo.rate.set(64);
    voice.vcf.cutoff.set(64);
    voice.osc.pwmDA.delay.set(0);
    voice.osc.pwmDA.attack.set(0);
    voice.pwmLFO.depth.set(64); //route
    voice.vcf.keyTracking.set(127 * .3);
    voice.vcfAccAmt.depth.set(127 * .25); //route
    voice.glideTime.set(127 * .25);
}

void loop() {
    while (Serial1.available())
        midi.handleByte(Serial1.read());

    //update OLED screen
//    char buffer[30]; //text buffer
//    u8g2.clearBuffer();
//
//    u8g2.setFont(u8g2_font_6x13_tr);
//    sprintf(buffer, "Byte: %d", test);
//    u8g2.drawStr(0, 10, buffer);
//    u8g2.sendBuffer();

    if (stepFlag) { //4kHz
        stepFlag = false;

        voice.update(); //glide, keytrack, etc
        touchStrip.poll();

        //TODO: remove. testing VCA with LFO output
        lfoRateDac.write(1 - voice.vcaADSR.output);

        NoteAssigner::update();
    }
}

//------------------------------------
struct CCbind { //binds MIDI CC number to Param
    uint8_t ccNumber;
    SimpleParam& param;
};

constexpr uint8_t PARAM_COUNT = 38;
const CCbind ccs[PARAM_COUNT] = {
    //{ 5, voice.glideTime },
    { 5, voice.osc.pwmADSR.attack },
    { 6, voice.osc.pwmADSR.decay },
    { 7, voice.osc.pwmADSR.sustain },
    { 8, voice.osc.pwmADSR.release },
    { 9,  voice.vcaADSR.attack },
    { 10, voice.vcaADSR.decay },
    { 11, voice.vcaADSR.sustain },
    { 12, voice.vcaADSR.release },
    { 13, voice.vcf.drive },
    { 14, voice.vcf.cutoff },
    { 15, voice.osc.waveform },
    { 16, voice.osc.pwm },
    { 17, voice.osc.pwmLFO.rate },
    { 18, voice.osc.pwmLFO.waveform },
    { 19, voice.pwmLFO.depth }, //route 0
    { 20, voice.osc.pwmLFO.reset },
    { 21, voice.osc.pwmDA.delay },
    { 22, voice.osc.pwmDA.attack },
    { 23, voice.osc.pwmADSR.sampHoldClock.rate },
    { 24, voice.osc.pwmLFO.slew },
    { 25, voice.keyTrack.depth }, //route 3
    { 26, voice.vcfAccAmt.depth }, //route 2
    { 27, voice.glideTime }, //TODO: put on CC 5
    /*
    { 28, voice.accentADSR.attack },
    { 29, voice.accentADSR.decay },
    { 30, voice.accentADSR.sustain },
    { 31, voice.accentADSR.release },
    */
        { 28, voice.lfo1.rate },
        // { 29, voice.lfo2.rate },
        // { 30, voice.routes[4].depth },
        { 29, voice.samphold1.rate },
        { 30, voice.samphold1.slew },
        { 31, voice.routes[5].depth },

    { 32, voice.lfo.rate },
    { 33, voice.lfo.waveform },
    { 34, voice.lfo.resetMode },
    { 35, voice.env.polarity },
    { 36, voice.pwmADSR.depth }, //route 1

    { 71, voice.vcf.resonance },
    { 72, NoteAssigner::notePriority },

    { 74, voice.env.attack },
    { 75, voice.env.decay },
    { 76, voice.env.sustain },
    { 77, voice.env.release },
};

void midiCcHandler(uint8_t cc, uint8_t val) {
    //find param with this CC number
    CCbind *result = (CCbind *) bsearch(&cc, ccs, PARAM_COUNT, sizeof(CCbind),
        [](const void *key, const void *ptr) -> int {
            int8_t ccNum = *(const uint8_t *) key;
            const CCbind *ccBind = (const CCbind *) ptr;

            return ccNum - (int8_t)ccBind->ccNumber;
        }
    );

    if (result) {
        result->param.set(val); //store raw value

        //TODO: buffer these strings and rate limit when screen/serial updates
        char buffer[Param::VAL_BUFFER_LEN] = {};
        Serial.println(result->param.fullName(buffer, sizeof(buffer)));
        Serial.println(result->param.toString(buffer, sizeof(buffer)));

        return;
    }

    switch (cc) {
        case 1: //Mod wheel
            lfoToPitchPot.write(val / 127.0);
            break;
        case 73: //Env depth
            envToVcfPot.write(val / 127.0); //Env to VCF
            break;
    }
}

//expo approximations
//    const float q = 64.0;
//    const float expoApprox = (!val) ? 100 : (normVal / (q + (1 - q) * normVal)) * 100;

//power law
//    const float w = 1 - (1/50); //0.996;
//    const float q = 10.7; //8.8;
//    float expoApprox = normVal - (w * (normVal - pow(normVal, q)));

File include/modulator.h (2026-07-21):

#pragma once
#include "Arduino.h"
#include "parameter.h"

class Modulator {
public:
    virtual void step() = 0;
    virtual void gateOn() {};
    virtual void gateOff() {};
    float output = 0;
    float scale = 1;

    Modulator* findOwner(const Param* param) { //return 'this' if we own a given Param
        //tests if a param is within our memory range, meaning we own it
        return (param >= (const void*)this && param < (const void*)(this + 1)) ? this : nullptr;
    }
protected: //consts for child classes
    static constexpr float TICK_RATE = 4000.0f;
    static constexpr float TICK_RATE_INV = 1/TICK_RATE;
};

class ValueSource : public Modulator {
public:
    float input = 0.0f; //write arbitrary value here to use as a modulator output

    void step() override {
        output = input;
    }
};

//LFO--------------------------------------------------------------------------
class SW_LFO : public Modulator {
public:
    enum Waveform : uint8_t { TRIANGLE, SQUARE, SINE, SAW, NOISE, WAVE_COUNT };

    SW_LFO(const char* p = "LFO"); //default prefix is LFO
    void step() override;
    void gateOn() override;
    void setRate(float rate);
    void setSlew(float rate);

    Param rate, waveform, reset, slew;
private:
    //list of Params that we manage on step()
    static constexpr Param SW_LFO::* Params[] = { &SW_LFO::rate, &SW_LFO::waveform, &SW_LFO::reset, &SW_LFO::slew };

    static constexpr const char* WaveformNames[] = {
        [TRIANGLE]  = "Triangle",
        [SQUARE]    = "Square",
        [SINE]      = "Sine",
        [SAW]       = "Saw",
        [NOISE]     = "Noise"
    };

    //make helper struct for Enum Params. Makes string function, converts/stores enum
    EnumParam<Waveform, WAVE_COUNT, WaveformNames, 9> _waveform;

    static constexpr uint32_t MAX = UINT32_MAX; //max count
    static constexpr uint32_t HALF_MAX = MAX / 2;
    static constexpr float MIN_HZ = 0.01f;
    static constexpr float MAX_HZ = 100.0f;
    static constexpr float RANGE = MAX_HZ / MIN_HZ; //precalc LFO range

    static constexpr float MIN_SLEW = 0.01f;
    static constexpr float MAX_SLEW = 100.0f;
    static constexpr float SLEW_RANGE = MAX_SLEW / MIN_SLEW; //precalc slew range

    const char* prefix;
    static const char* getRateStr(char* buffer, size_t size, uint8_t value);
    static const char* getSlewStr(char* buffer, size_t size, uint8_t value);
    static const char* getPhaseStr(char* buffer, size_t size, uint8_t value);

    float _rate = .01;
    uint32_t _stepSize = 1;
    uint32_t _phase = 0;
    float _slewRate = 0;
    float _previousValue = 0;
    float _currentSlewed = 0;
};

//Clock------------------------------------------------------------------------
class SW_CLOCK : public Modulator {
public:
    SW_CLOCK(const char* p);
    void step() override;
    void gateOn() override;
    void setRate(float rate);
    bool output = false;
    bool sync = true;

    Param rate;
private:
    //list of Params that we manage on step()
    static constexpr Param SW_CLOCK::* Params[] = { &SW_CLOCK::rate };
    static constexpr uint32_t MAX = UINT32_MAX; //max count
    static constexpr uint32_t HALF_MAX = MAX / 2;
    static constexpr float MIN_HZ = 4.0f;
    static constexpr float MAX_HZ = 200.0f;
    static constexpr float RANGE = MAX_HZ / MIN_HZ; //precalc LFO range

    const char* prefix;
    static const char* getRateStr(char* buf, size_t len, uint8_t v);

    float _rate = 1;
    uint32_t _stepSize = 1;
    uint32_t _phase = 0;
};

//ADSR-------------------------------------------------------------------------
class SW_ADSR : public Modulator {
public:
    //PWM stages are first, then sustain
    enum Stage { ATTACK, DECAY, RELEASE, SUSTAIN, STAGE_COUNT};
    //enum Mode { ADSR, ASR, AD };
    SW_ADSR(const char* p);
    void step() override;
    void setRate(Stage stage, float newRate);
    void setSustain(float sustain);

    void gateOn() override;
    void gateOff() override;

    SW_CLOCK sampHoldClock { "ADSR" }; //TODO add prefix support

    Param attack, decay, sustain, release;
private:
    //list of Params that we manage on step()
    static constexpr Param SW_ADSR::* Params[] = { &SW_ADSR::attack, &SW_ADSR::decay, &SW_ADSR::sustain, &SW_ADSR::release };
    struct stage {
        float minPeriod;
        float maxPeriod;
        float range;

        float alpha; //used in RC curve math
        float rate;
        float target; //value to move towards
    };

    const char* prefix;

    static constexpr float MIN_RATE = .0001;

    stage _stages[3]; //hold all PWM stages
    Stage _currentStage;

    float _phase = 0;
};

//Delay Attack-----------------------------------------------------------------
class SW_DA : public Modulator {
public:
    //PWM stages are first, then sustain
    enum Stage { DELAY, ATTACK, STALL };
    SW_DA(const char* p);
    void step() override;
    void setRate(Stage stage, float newRate);

    void gateOn() override;
    void gateOff() override;

    Param delay, attack;
private:
    //list of Params that we manage on step()
    static constexpr Param SW_DA::* Params[] = { &SW_DA::delay, &SW_DA::attack };
    struct stage {
        float minPeriod;
        float maxPeriod;
        float range;

        float alpha; //step size
        float rate;
    };

    const char* prefix;

    static constexpr float MIN_RATE = .0001;

    stage _stages[3]; //hold all PWM stages
    Stage _currentStage;

    float _phase = 0;
};

//Slew processor---------------------------------------------------------------
class SH_Slew : public Modulator {
public:
    SH_Slew(const char* p);
    void step() override;
    void gateOn() override;
    void setRate(float rate);
    void setSlew(float rate);
    bool sync = true;

    Param input, rate, slew;
private:
    //list of Params that we manage on step()
    static constexpr Param SH_Slew::* Params[] = { &SH_Slew::input, &SH_Slew::rate, &SH_Slew::slew };

    static constexpr uint32_t MAX = UINT32_MAX; //max count
    static constexpr uint32_t HALF_MAX = MAX / 2;
    static constexpr float MIN_HZ = 4.0f;
    static constexpr float MAX_HZ = 200.0f;
    static constexpr float RANGE = MAX_HZ / MIN_HZ; //precalc LFO range

    static constexpr float MIN_SLEW = 0.01f;
    static constexpr float MAX_SLEW = 100.0f;
    static constexpr float SLEW_RANGE = MAX_SLEW / MIN_SLEW; //precalc slew range

    const char* prefix;
    static const char* getRateStr(char* buf, size_t len, uint8_t v);
    static const char* getSlewStr(char* buffer, size_t size, uint8_t value);

    uint32_t _stepSize = 1;
    uint32_t _phase = 0;

    float _slewRate = 0;
    float _currentSlewed = 0;

    float _targetValue = 0;
};

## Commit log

2026-06-03 Adding WIP Schems
    [SX-150 Mk II (MIDI THT Proto E7).brd, SX-150 Mk II (MIDI THT Proto E7).sch]
2026-06-05 Moving PWM modulators into Osc
2026-06-19 Adding noise LFO waveform and slew setting
    [hw_lfo.cpp, main.cpp, modulator.h]
2026-06-20 Improving params for HW_LFO, and adding reset modes Moving functionality out of main into noteAssigner
    [hw_adsr.cpp, hw_lfo.cpp, hw_lfo.h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]
2026-06-23 Adding Routes to route modulation
    Rename some classes for consistency
    Fix issue of redefined "output" for modulators
    Adding "SimpleParam" for non-modulated Params
    [hw_adsr.cpp, hw_vco.cpp, main.cpp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]
2026-07-21 Added Sample/Hold + slew modulator

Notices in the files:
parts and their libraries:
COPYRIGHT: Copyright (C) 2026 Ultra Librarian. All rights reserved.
